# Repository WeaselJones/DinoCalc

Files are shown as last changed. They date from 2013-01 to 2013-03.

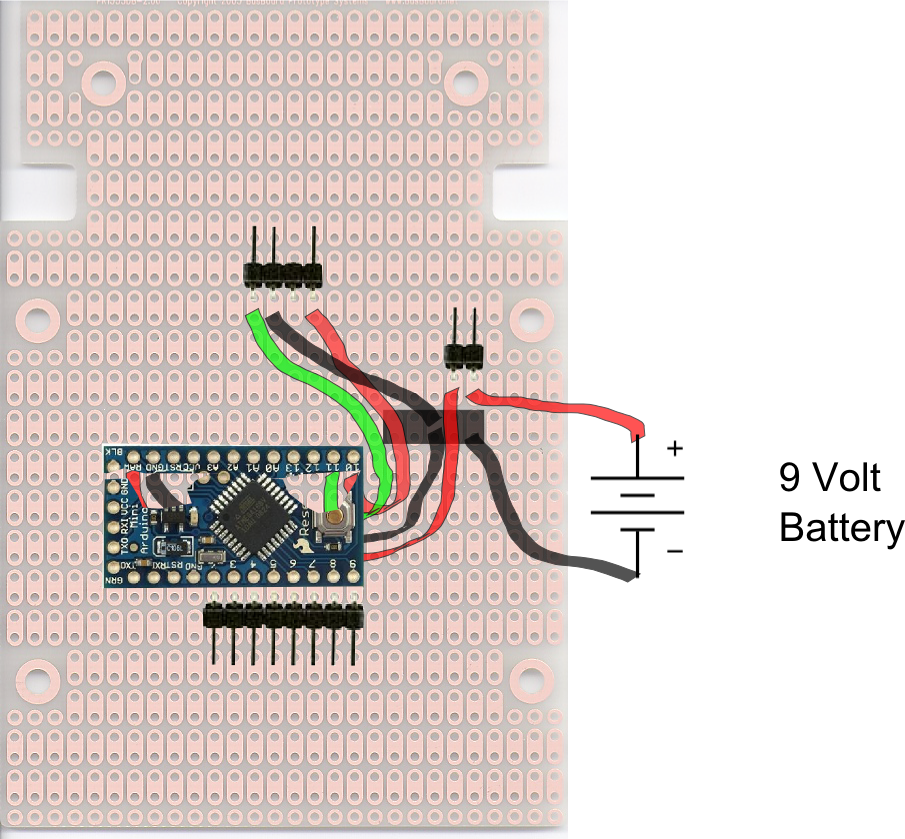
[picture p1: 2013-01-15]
Hardware/Hardware Layouts/Hardware Layout Version 1v0.png

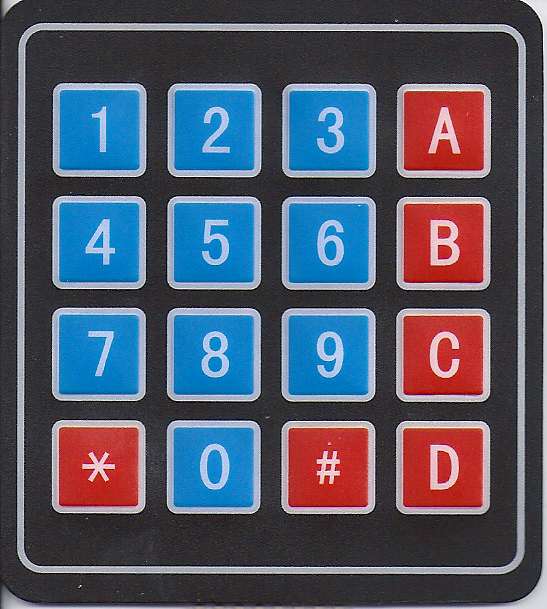
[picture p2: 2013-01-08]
Hardware/Inkscape files/4x4 keypad0001.tif

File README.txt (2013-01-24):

DinoCalculator Version 1.0

Download updates from:
http://code.google.com/p/dinocalc/

Summary:
When I was younger I had a calculator that did not have a LCD display but instead 
had two LED lights, one green and one red.  You would enter a math problem with what 
you thought the correct answer was (for example, type 12 + 12 = 24, and then press 
the "?" key).  If your answer was right the green LED would light up, if your answer 
was wrong, the red LED would light up.

This is my salute to that toy from my childhood, as well as a great way for me to 
engineer and program a neat little project that my preschool son can actually use 
to check his simple math.

This first part will document the prototype that I have built.  My first objective 
was to create a calculator capable of just adding and subtracting using off the 
shelf items.  I plan on starting with an Arduino Pro Mini for the developmental 
and prototype stage and once I can get most of the major bugs worked out I will 
then move on to a final version that has a lower cost and device count (ATmega328P
on a custom PCB).  

Future objectives (not in any particular order) will be to:

1) Replace the Arduino Pro Mini board with a custom made PCB and reduce parts to 
a minimum to lower costs (I already have several friends wanting versions for 
their kids)

2) Add multiplication and division to the calculator's capabilities (low priority 
for me since this will involve more keys then a 4x4 matrix keypad and my son is 
only starting addition and subtraction right now)

3) Develop a custom keypad (maybe using tactile buttons and caps, or making my 
own "membrane" type keypad, or exploring "conductive" type buttons)

4) Add sound for errors or beep whenever custom keypad button is pressed

5) Develop code so that it could also be used for a "math" type game for multiple 
players. For example, Display a math problem and contestants enter answer on their 
calculators. If their answer is right, their token moves away from some peril 
(like a chomping dinosaur) and if wrong moves closer to peril. Loser is the one 
that gets eaten (chomp,chomp,chomp)

6) Make the circuit low-power for longer battery life and replace the 9V battery 
with two NiMH AA batteries or perhaps even a button cell rechargeable battery

7) Add a recharging circuit to recharge the rechargeable batteries from USB

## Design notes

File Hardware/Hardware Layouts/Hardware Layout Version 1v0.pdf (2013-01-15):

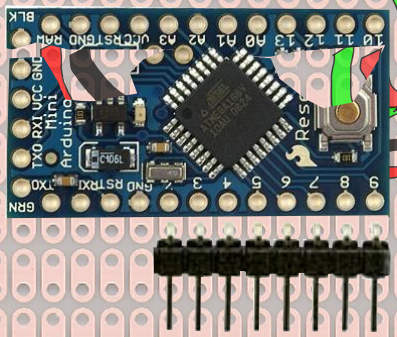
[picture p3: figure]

9 Volt
Battery

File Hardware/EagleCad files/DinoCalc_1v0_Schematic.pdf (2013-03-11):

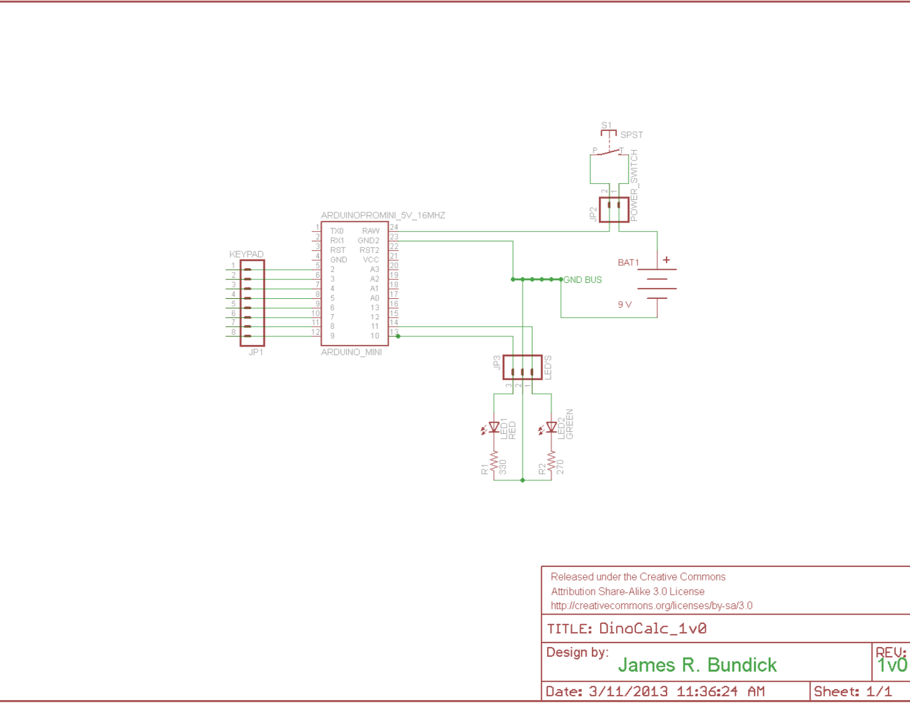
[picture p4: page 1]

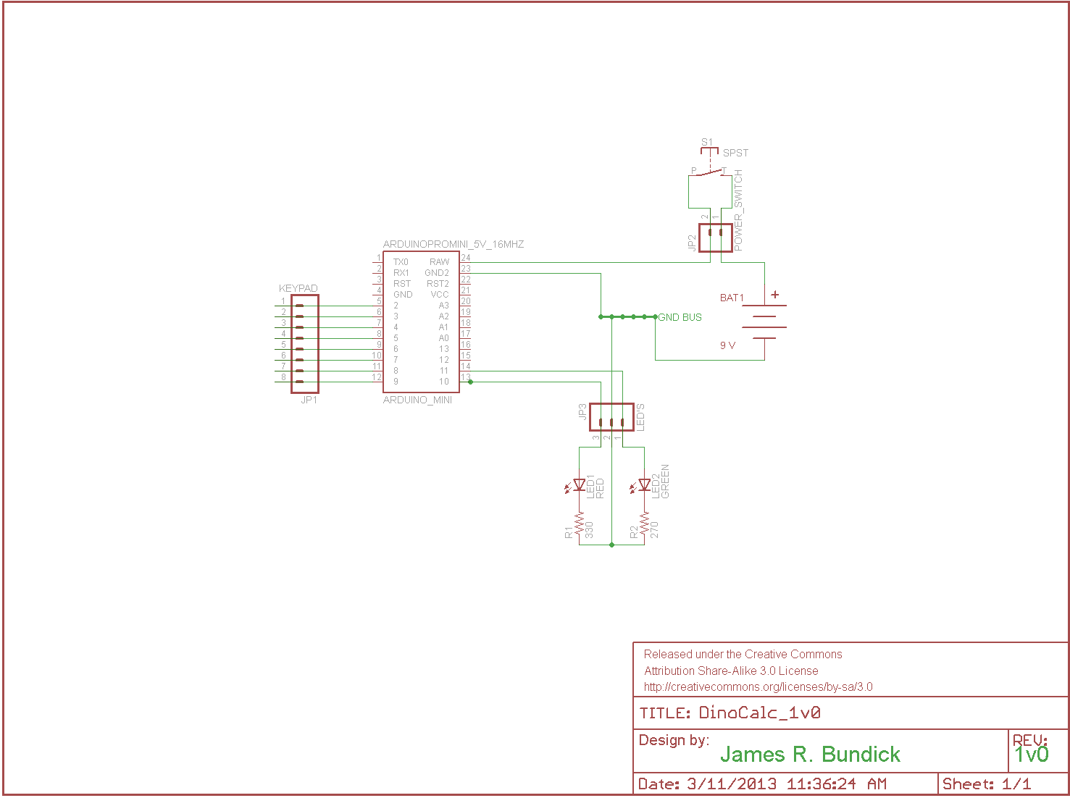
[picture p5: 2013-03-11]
Hardware/EagleCad files/DinoCalc_1v0_Schematic.png

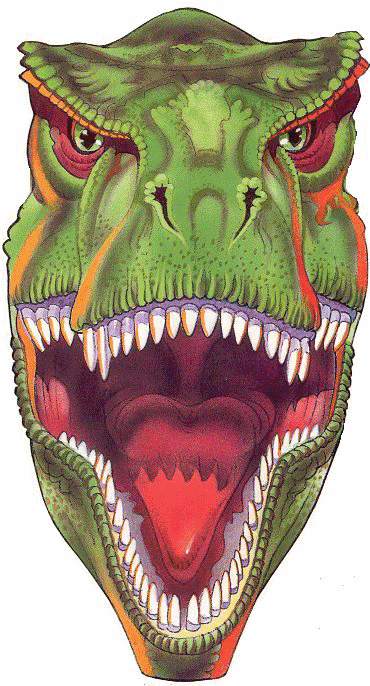
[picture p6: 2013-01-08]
Hardware/Inkscape files/face.gif

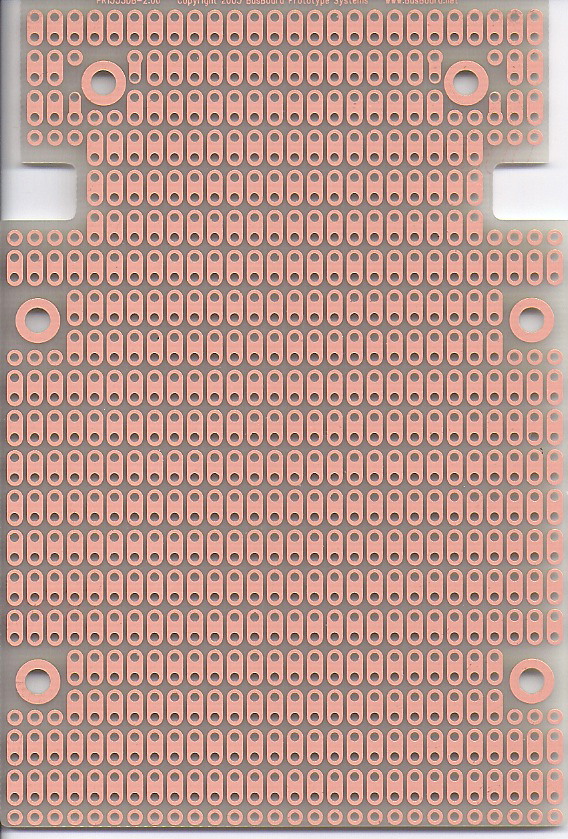
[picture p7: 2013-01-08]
Hardware/Inkscape files/Protoboard Blank Layout.tif

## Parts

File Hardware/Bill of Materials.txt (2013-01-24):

DinoCalc Hardware version 1.0 (Prototype stage)

Below is a listing of parts used in the Prototype stage of 
the DinoCalculator.  The Bill of Materials is listed in three 
parts from Mouser.com, Sparkfun.com, and Amazon.com.
Omit any parts you might already have and feel free to use
your favorite source(s) for parts.

----------------------------------------------------
BOM 1 of 3  MOUSER.COM  
----------------------------------------------------

Item
No.   Qty   Description                            Part Number
--    ---   -------------------------------------  ----------------
1)     1    9v Alkaline Battery                    658-6LR61XWA
2)     1    CARBON FILM RESISTOR - 330 OHMS        291-330-RC
3)     1    CARBON FILM RESISTOR - 270 OHMS        291-270-RC
4)     1    SPST ON-OFF SLIDE SWITCH               112-R13-602A
5)     1    LED - THROUGH HOLE GREEN DIFFUSED      78-TLHG5400
6)     1    LED - THROUGH HOLE RED DIFFUSED        78-TLHR5400
7)     2    5MM LED PANEL MOUNTING                 696-SSH-LX5091
8)     1    4X4 MATRIX MEMBRANE KEYPAD             619-27899
9)     1    PROTOTYPE BOARD FOR 1553DBKBAT ENC     854-PR1553DBAT
10)    1    HAND HELD ENC WITH BATT COMPARTMENT    546-1553DBKBAT

You can find this Bill of Material on the mouser.com website under
the DinoCalc version 1.0 project at the following link:
  
http://www.mouser.com/ProjectManager/ProjectDetail.aspx?AccessID=0904c64079

----------------------------------------------------
BOM 2 of 3  SPARKFUN.COM
----------------------------------------------------

Item
No.   Qty   Description                            Part Number
--    ---   -------------------------------------  ----------------
1)     1    Arduino Pro Mini 328 - 5V/16MHz        DEV-11113
2)     1    FTDI Basic Breakout - 5V               DEV-09716  (Optional)
3)     1    Female Headers                         PRT-00115  (Optional)
4)     1    Break Away Headers - Straight          PRT-00116
5)     1    Break Away Male Headers - Right Angle  PRT-00553  
6)     1    Solderless Headers - 10-pin Straight   PRT-10527  (Optional)
7)     1    Jumper Wire - PTH Black White          PRT-08672  (Optional)
8)     1    Jumper Wire - 0.1", 3-pin, 6"          PRT-10368  (Optional)
9)     1    Hook-up Wire - Red                     PRT-08023  (Optional)
10)    1    Hook-up Wire - Black                   PRT-08022  (Optional)

Notes:
Item #2:  This is needed if you don't already have a way to program the Arduino Pro Mini.
          DEV-09718 5V FTDI Cable will also work and you won't need to find a USB Cable.
Item #3:  This is needed if you don't want to make the Arduino Pro Mini a permanent
          installation in your calculator and you want to reuse it for a later project.
Item #6:  This can be used in place of soldering headers to the Arduino Pro Mini 
          Programming Header.
Items #7 and #8:  These are recommended only if you don't already have some old jumper 
          wires (such as CD-ROM kits or from old computer boards) laying around.
Items #9 and #10:  Hook-up Wire is needed only if you don't already have a source of 
          22 AWG wire for the wiring on the protoboard.

You can find this Bill of Material in a Wish List on Sparkfun.com at:
https://www.sparkfun.com/wish_lists/56143

----------------------------------------------------
BOM 3 of 3  AMAZON.COM
----------------------------------------------------

This was the adhesive paper purchased to place over
the keypad and on the enclosure face.

Item
No.   Qty   Description                            
--    ---   -------------------------------------  
1)     1    Avery Sticker Project Paper, White, 8.5 x 11 Inches, Pack of 15 (03383)

found at link:  http://www.amazon.com/gp/product/B0000C0CJQ/ref=oh_details_o04_s00_i00

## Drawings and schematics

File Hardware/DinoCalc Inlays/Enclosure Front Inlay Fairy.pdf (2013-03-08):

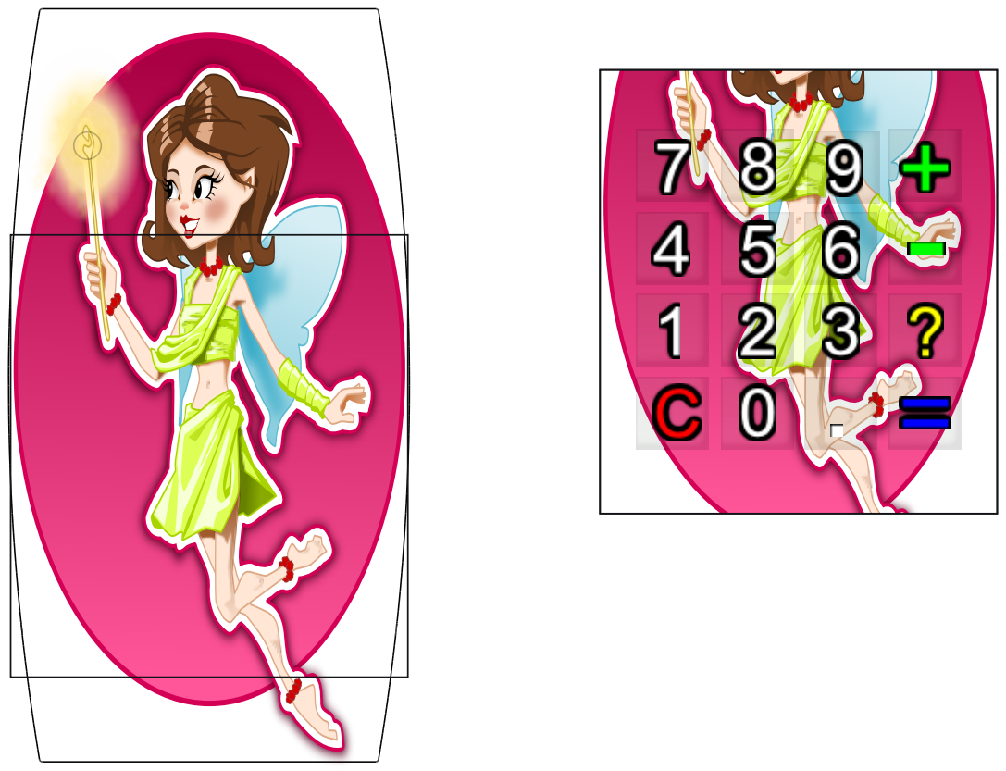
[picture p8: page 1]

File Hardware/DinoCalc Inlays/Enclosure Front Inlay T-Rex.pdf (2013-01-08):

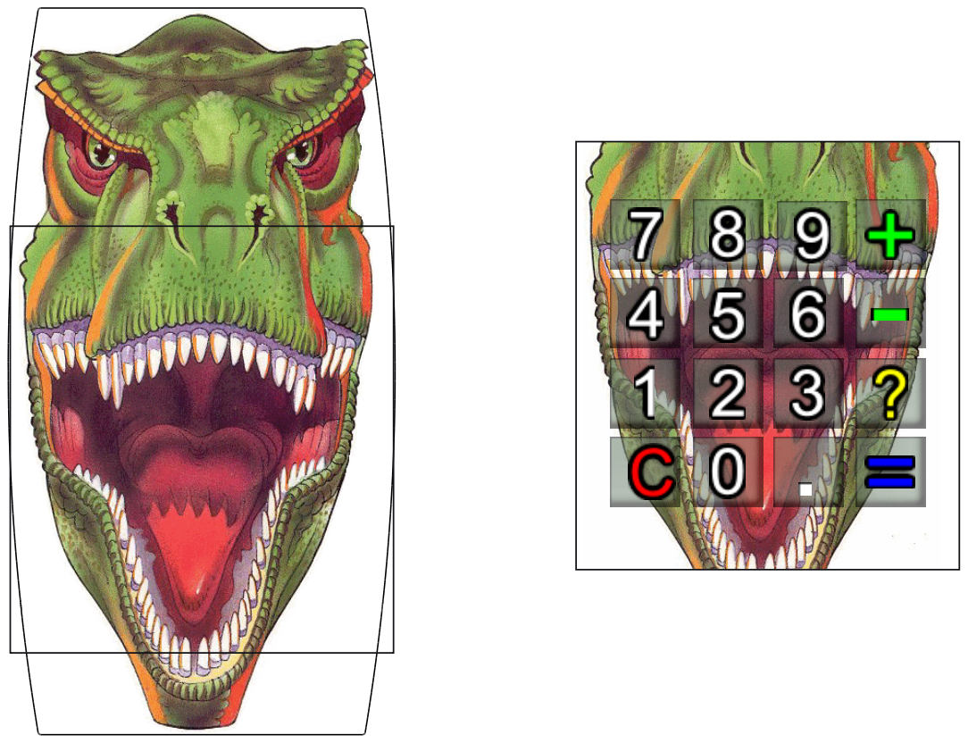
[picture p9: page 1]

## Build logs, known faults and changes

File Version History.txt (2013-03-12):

DinoCalculator Release 1v0

Hardware Version History

1.0 2012-12-31 - JRB: Prototype with Arduino Pro Mini (5V/16MHz)

Software Version History

1.0 2012-12-31 - JRB: RELEASE VERSION. Changed keypad matrix to match 
the layout I printed on the keypad sticker. Added blinkLEDs() to show 
activity when calculator is first powered ON. Commented out Serial 
commands and printInfo(), program size went from ~12,000 bytes to 
9,868 bytes.

0.5 2012-12-22 - JRB: Changed x,y,z,z2 from integers to floating
for "real" number calculations. Since floating point math is not 
completly exact http://arduino.cc/en/Reference/Float I added code 
to check that the absolute value of the difference between the 
calculated answer and the entered answer is less than some small 
number. Reformated text layout for printing.

0.4c 2012-12-22 - JRB: WORKING VERSION of adding and subtracting
whole numbers only. Negative number adding and subtracting is also 
supported. Minus key can be used for negative numbers now, not just 
subtraction. (ie, can now enter "-3 + -5 = -8")

0.4b 2012-12-21 - JRB: Added condition to prevent "?" from giving
false "correct"

0.4 2012-12-19 - JRB: Added more information to program
description. Added comparison of user entered answer to calculated answer. 
Added Green and Red LED code for correct and wrong answer results. Changed 
code to allow negative number answers.

0.3 2012-12-18 - JRB: Corrected minor string issue with equal sign attaching 
to stringOne after calculation. Cleaned up serial commands for debugging.

0.2 2012-12-17 - JRB: Worked on code to add multi-digit numbers
instead of single digit numbers by doing conversion of strings to integers.

0.1 2012-12-17 - JRB: Got Code working to read key presses of membrane 4x4 keypad. 
Serial print commands added for debugging and will be commented out when code is stable.

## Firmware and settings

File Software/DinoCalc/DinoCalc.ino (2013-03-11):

/* DinoCalc Calculator Software 1v0
   by James R. Bundick (weaseljones@gmail.com)
   Programmed using Arduino IDE 1.0.3
................................................................
License
The library, Keypad.h version 3.0, was used without modification
and is authored by Mark Stanley and Alexander Brevig
which they released under the GNU LGPL 2.1 license.

The rest of the code done by myself is released under 
the MIT License  http://opensource.org/licenses/MIT
Copyright (c) 2012 James R. Bundick

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
THE SOFTWARE IS PROVIDED "AS IS", WITHOUT WARRANTY OF ANY KIND, 
EXPRESS OR IMPLIED, INCLUDING BUT NOT LIMITED TO THE WARRANTIES 
OF MERCHANTABILITY, FITNESS FOR A PARTICULAR PURPOSE AND 
NONINFRINGEMENT. IN NO EVENT SHALL THE AUTHORS OR COPYRIGHT 
HOLDERS BE LIABLE FOR ANY CLAIM, DAMAGES OR OTHER LIABILITY, 
WHETHER IN AN ACTION OF CONTRACT, TORT OR OTHERWISE, ARISING 
FROM, OUT OF OR IN CONNECTION WITH THE SOFTWARE OR THE USE OR 
OTHER DEALINGS IN THE SOFTWARE.
................................................................

Summary:
When I was younger I had a calculator that did not have a LCD display but 
instead had two LED lights, one green and one red.  You would enter a math 
problem with what you thought the correct answer was (for example, 
12 + 12 = 24, and then press the "?" key).  If your answer was right the 
green LED would light up, if your answer was wrong, the red LED would light 
up.

This is my salute to that toy from my childhood, as well as a great way for 
me to engineer and program a neat little project that my preschool son can 
actually use to check his simple math.

This first part will document the prototype that I have built.  My first 
objective was to create a calculator capable of just adding and subtracting 
using off the shelf items.  I plan on starting with an Arduino Pro Mini for 
the developmental and prototype stage and once I can get most of the major 
bugs worked out I will then move on to a final version that has a lower cost 
and device count (ATmega328p on a custom PCB).  


Future objectives (not in any particular order) will be to:

1) Replace the Arduino Pro Mini board with a custom made PCB and reduce parts 
to a minimum to lower costs (I already have several friends wanting versions 
for their kids)

2) Add multiplication and division to the calculator's capabilities (low 
priority for me since this will involve more keys then a 4x4 matrix keypad 
and my son is only starting addition and subtraction right now)

3) Develop a custom keypad (maybe using tactile buttons and caps, or making my
own "membrane" type keypad, or exploring "conductive" type buttons)

4) Add sound for errors or beep whenever custom keypad button is pressed

5) Develop code so that it could also be used for a "math" type game for multiple
players. For example, Display a math problem and contestants enter answer on their 
calculators. If their answer is right, their token moves away from some peril (like
a chomping dinosaur) and if wrong moves closer to peril. Loser is the one that gets
eaten (chomp,chomp,chomp)

6) Make the circuit low-power for longer battery life and replace the 9V battery
with two NiMH AA batteries or perhaps even a “button” cell rechargeable battery

7) Add a recharging circuit to recharge the rechargeable batteries from USB


References used during development:
1)  http://tronixstuff.wordpress.com/tutorials  > Arduino Tutorials,
    chapter 42a, Keypads II
2)  http://www.arduino.cc/playground/Code/Keypad by Mark Stanley, 
    Alexander Brevig 
3)  "Arduino Cookbook", 2nd edition, by Michael Margolis
4)  "BlinkWithoutDelay" example by David A. Mellis and Paul 
     Soffregen that came with Arduino IDE 1.0.3 
5)  Floating number math with Arduino,
    http://arduino.cc/en/Reference/Float 

Bill of Material for prototype:
1)  Arduino Pro Mini 5V/16MHz from Sparkfun.com
2)  4x4 Matrix keypad purchased on Amazon.com
3)  Red LED
4)  Green LED
5)  330 ohm resistor, 270 ohm resistor
6)  SPST switch (used SPDT because that is what I had)
7)  Female and Male Headers (Sparkfun.com)
8)  Protobox - 1553DBAT-BK KIT from Busboard Prototye Systems
    Purchased on Amazon.com
    (Includes:  Enclosure, PCB, screws, battery clips)
9)  Hook-up Wire
10) 9V Battery
11) Avery Adhesive Sticker Paper
    Purchased on Amazon.com
12) Heat Shrink (Radio Shack)
13) LED holders (Radio Shack)

Hardware layout:
Keypad:  4x4 Matrix Membrane keypad 
          
          1  2  3  A 
          4  5  6  B
          7  8  9  C
          *  0  #  D
          
         Each Row and Each Column connects to a PIN for total of 
         8 pins.
         Row 1 >> Pin 1      Column 1 >> Pin 5
         Row 2 >> Pin 2      Column 2 >> Pin 6
         Row 3 >> Pin 3      Column 3 >> Pin 7
         Row 4 >> Pin 4      Column 4 >> Pin 8

Arduino D 2 ---> 4x4 keypad pin 1
Arduino D 3 ---> 4x4 keypad pin 2
Arduino D 4 ---> 4x4 keypad pin 3
Arduino D 5 ---> 4x4 keypad pin 4
Arduino D 6 ---> 4x4 keypad pin 5
Arduino D 7 ---> 4x4 keypad pin 6
Arduino D 8 ---> 4x4 keypad pin 7
Arduino D 9 ---> 4x4 keypad pin 8
Arduino D10 ---> (long leg)RED LED(short leg) ---> 
                     330 ohm resistor ---> GND
Arduino D11 ---> (long leg)GRN LED(short leg) ---> 
                     270 ohm resistor ---> GND


Software Logic

1) User enters First Number, then math operator, then Second
   Number, then equal sign, then user's answer, then "?"
   [12 + 12 = 12 ? <-- User's guess]
2) Microprocessor calculates answer to First Number, math 
   operator, Second Number 
   [12 + 12 = 24  <-- Calculated answer]
3) Microprocessor compares calculated answer to  User Inputed 
   Answer.  If they are not equal then light red LED.  If they
   are equal then light green LED. 
   [12 != 24, so light red LED]

Version History
1.0  2012-12-31 - JRB:  RELEASE VERSION.  Changed keypad matrix to
      match the layout I printed on the keypad sticker.  Added
      blinkLEDs() to show activity when calculator is first powered
      ON.  Commented out Serial commands and printInfo(), program
      size went from ~12,000 bytes  to 9,868 bytes.
      
0.5  2012-12-22 - JRB:  Changed x,y,z,z2 from integers to floating
      for "real" number calculations. Since floating point math
      is not completly exact http://arduino.cc/en/Reference/Float 
      I added code to check that the absolute value of the 
      difference between the calculated answer and the entered 
      answer is less than some small number.  
      Reformated text layout for printing.

0.4c 2012-12-22 - JRB:  WORKING VERSION of adding and subtracting
      whole numbers only.  Negative number adding and subtracting
      is also supported.  Minus key can be used for negative 
      numbers now, not just subtraction. 
      (ie, can now enter "-3 + -5 = -8")
           
0.4b 2012-12-21 - JRB: Added condition to prevent "?" from giving
      false "correct"

0.4 2012-12-19 - JRB: Added more information to program 
      description.  Added comparison of user entered answer to 
      calculated answer.  Added Green and Red LED code for 
      correct and wrong answer results.  Changed code to allow 
      negative number answers.
                      

0.3 2012-12-18 - JRB: Corrected minor string issue with equal sign
      attaching to stringOne after calculation.  Cleaned up serial
      commands for debugging.

0.2 2012-12-17 - JRB: Worked on code to add multi-digit numbers 
      instead of single digit numbers by doing conversion of 
      strings to integers.

0.1 2012-12-17 - JRB: Got Code working to read key presses of 
      membrane 4x4 keypad.  Serial print commands added for 
      debugging and will be commented out when code is stable.

*/

#include "Keypad.h" // http://www.arduino.cc/playground/Code/Keypad by Mark Stanley, Alexander Brevig 
    

const byte ROWS = 4; //four rows
const byte COLS = 4; //four columns
char keys[ROWS][COLS] =
 {{'7','8','9','+'}, //Sticker will be applied over keypad to 
  {'4','5','6','-'}, //match the layout I want and to provide 
  {'1','2','3','?'}, //a custom graphic (eg dinosaur, bird, etc)
  {'C','0','.','='}};// 
byte rowPins[ROWS] = {
  2, 3, 4, 5}; //Arduino pins that connect to the row pinouts of the keypad pins 1 through 4.
byte colPins[COLS] = {
  6, 7, 8, 9}; //Arduino pins that connect to the column pinouts of the keypad pins 5 through 8.

Keypad keypad = Keypad(makeKeymap(keys), rowPins, colPins, ROWS, COLS);

const int ledGRN = 11;  //Arduino output for Green LED
const int ledRED = 10;  //Arduino output for Red LED

long previousMillis = 0; //used to light LED without using delay()
long interval = 3000;  //maximum time to leave LED HIGH (on)

float x; //first number that is entered by user
float y; //second number that is entered by user
float z; //calculated answer
float z2; //answer that is entered by user
int h;  //used to indicate if "." has been pressed already
int i;  //placeholder for operator (i=1 for addition, i=2 for subtraction)
int j;  //used to indicate to program that it is time for the user to input an answer

String stringOne;   //Placeholder for First Number entered by user
String stringTwo;   //Placeholder for Second Number entered by user                                                     
String stringThree; //stringThree is used to show operator and if equal has been pressed.
String stringFour;  //Placeholder for Guessed Answer entered by user                                                     
                                                       
void setup()
{
//  Serial.begin(9600); //for debugging

  pinMode (ledGRN, OUTPUT); //sets up the Arduino pins as outputs
  pinMode (ledRED, OUTPUT);
  
  stringOne = String ();
  stringTwo = String ();
  stringThree = String ();
  stringFour = String ();

  x = 0;
  y = 0;
  z = 0;
  z2 = 0;
  h = 0;
  i = 0;
  j = 0;
  blinkLEDs();
}

void loop()
{
  unsigned long currentMillis = millis();       //Make sure LED doesn't stay continuously on, 
  if(currentMillis - previousMillis > interval) //but allow the code to continue without a delay.
  {                                             
    digitalWrite (ledGRN, LOW);                 
    digitalWrite (ledRED, LOW);                 
  }


  char key = keypad.getKey();
  switch (key)
  {
    case 'C':    //If 'C' is pressed then clear calculator
      blinkLEDs();
      clearCalc();
      break;
    
    case '?':    //Calculate answer and compare it to the answer that was entered by the user
      if (j == 3)
      {
        calcAnswer();
      }
      else
      {
        stringThree = "ERROR";  //if '?' is pressed too soon, error out
//        printInfo();
        showError();
        clearCalc();
      }
      break;
    
    case '=':    //Get ready for the answer to be entered by user
      if (j == 2)
      {
        h = 0;  //h = 0 to allow "." to be used in Answer
        j = 3;  //change j to 3 when equal key has been used once
        stringThree = stringThree + key;
//        printInfo();
      }    
      else
      {
        stringThree = "ERROR";  //if equal is pressed too soon, error out
//        printInfo();
        showError();
        clearCalc();
      }
      break;

    case '+':
      if (i == 0)
      {
        h = 0;  //h = 0 to allow "." to be used for Number2
        i = 1;  //i = 1 to denote addition
        j = 1;  //j = 1 to indicate operator has been pressed, now get Number2
        stringThree = stringThree + key;
//        printInfo();
      }    
      else
      {
        stringThree = "ERROR"; //if plus is pressed multiple times, error out
//        printInfo();
        showError();
        clearCalc();
      }
      break;
  
    case '-':
      if (i == 0)
      {
        if (stringOne == "") //If '-' is the first digit pressed for Number1,
        {                    //use '-' to indicate Number1 is a negative number
          stringOne = stringOne + key;
        }
        else
        {
          h = 0;  //h = 0 to allow "." to be used for Number2
          i = 2;  //i = 2 to denote subtraction
          j = 1;  //j = 1 to indicate operator has been pressed, now get Number2
          stringThree = stringThree + key;
        }
//        printInfo();  
      }    
      else
      {
        if (j == 3 && stringFour == "")  //equal key has been pressed once,
        {                                //if '-' is first digit of answer,
          stringFour = stringFour + key; //answer is a negative number
//          printInfo();
        }
        else
        {
          if (stringTwo == "") //if '-' is first digit of Number2, Number2 is a negative number
          {
            stringTwo = stringTwo + key;
//            printInfo();
          }
          else
          {
            stringThree = "ERROR";  //if minus is pressed and is not operator or first digit of number, error out
//            printInfo();
            showError();
            clearCalc();
          }
        }
      }
      break;
  
    case '.':
      if (h == 0)
      {
        h = 1;  //denotes a decimal point has been used once
        if (j == 0)
        {
          stringOne = stringOne + key; //adds decimal to Number1
        }
        if (j == 1 || j == 2)
        {
          stringTwo = stringTwo + key; //adds decimal to Number2
        }
        if (j == 3)
        {
          stringFour = stringFour + key; //adds decimal to Answer
        }
//        printInfo();
     }
     else
     {
       stringThree = "ERROR";  //if you try and enter a second decimal point in a number, error out
//       printInfo();
       showError();
       clearCalc();
     }
     break;

    default:
      if (key != NO_KEY)
      {
        digitalWrite (ledGRN, LOW); //Turn off LED's if they are on
        digitalWrite (ledRED, LOW);

        if (i == 0) //entering Number1
        {
          stringOne = stringOne + key;
        }
        if ((i == 1 || i == 2) && j != 3) //entering Number2, '=' has not been pressed
        {
          stringTwo = stringTwo + key;
          j = 2; //indicated operator has already been used
        }
        if (j == 3) //'=' has been pressed, entering User's answer
        {
          stringFour = stringFour + key;
        }
//        printInfo();
    }
  }
}

void calcAnswer ()  //Calculate answer and compare to user's answer
{
  char charBufx[50]; //might be able to reduce number from 50
  char charBufy[50];
  char charBufz2[50];
  stringOne.toCharArray(charBufx,50);   //convert String to char array
  stringTwo.toCharArray(charBufy,50);   //convert String to char array
  stringFour.toCharArray(charBufz2,50); //convert String to char array

  x = atof(charBufx);   //convert char array to float
  y = atof(charBufy);   //convert char array to float
  z2 = atof(charBufz2); //convert char array to float

  if (i == 1) //operator was addition
  {
    z = x + y;  //Calculate answer
    stringThree = " + ";
  }
  if (i == 2) //operator was subtraction
  {
    z = x - y;  //Calculate answer
    stringThree = " - ";
  }

  float a;     
  a = z2 - z;  //since floating point math is not completly exact, http://arduino.cc/en/Reference/Float 
               //check that the absolute value of the difference between the numbers is less than some small number. 

//.......................................................
//  Print to Serial for Debugging
/*    Serial.print ("\nCalculated answer:");
    Serial.print (x,4);
    Serial.print (stringThree);
    Serial.print (y,4);
    Serial.print (" = ");
    Serial.print (z,4);
    Serial.print ("\nEntered answer:");
    Serial.print (x,4);
    Serial.print (stringThree);
    Serial.print (y,4);
    Serial.print (" = ");
    Serial.print (z2,4);
    Serial.print ("\nDifference between answers:"); 
    Serial.print (a,12);
*/    
//.......................................................
 
  if (abs(a) < 0.000001) //since floating point math is not completly exact http://arduino.cc/en/Reference/Float 
  {                      //check that the absolute value of the difference between the numbers is less than some small number. 
//    Serial.print ("\nCORRECT!!!"); //for Debugging
    digitalWrite (ledGRN, HIGH);
    digitalWrite (ledRED, LOW);
    previousMillis = millis();   
  }
  else
  {
//    Serial.print ("\nWRONG!!!");  //for Debugging
    digitalWrite (ledGRN, LOW);
    digitalWrite (ledRED, HIGH);
    previousMillis = millis();   
  }
  clearCalc();  //get ready for next math problem
}

/*void printInfo ()  //Used for Debugging
{
     Serial.print ("\nString1 : ");
     Serial.println (stringOne);
     Serial.print ("\nString2 : ");
     Serial.println (stringTwo);
     Serial.print ("\nString3 : ");
     Serial.println (stringThree);
     Serial.print ("\nString4 : ");
     Serial.println (stringFour);
}
*/

void clearCalc() //Get ready for next math problem
{
    Serial.println ("\ncleared\n\n\n");  //for debugging

    stringOne = "";
    stringTwo = "";
    stringThree = "";
    stringFour = "";
    x = 0;
    y = 0;
    z = 0;
    h = 0;
    z2 = 0;
    i = 0;
    j = 0;
     
   char key = NO_KEY;
}

void showError() //Blink RED LED to show Errors
{
  for (int k=0; k <10; k++) 
  {
    digitalWrite (ledGRN, LOW);
    digitalWrite (ledRED, HIGH);
    delay (50);
    digitalWrite (ledGRN, LOW);
    digitalWrite (ledRED, LOW);
    delay (50);
  }   
}

void blinkLEDs()
{
  for (int k=0; k <5; k++) //flash LED's so you know something is going on
  {
    digitalWrite (ledGRN, HIGH);
    digitalWrite (ledRED, HIGH);
    delay (50);
    digitalWrite (ledGRN, LOW);
    digitalWrite (ledRED, LOW);
    delay (50);
  }  
} 

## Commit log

2013-01-04 Bill of Material link to Mouser.com
2013-01-07 Create Sparkfun BOM
2013-01-07 Update Hardware/Sparkfun BOM
2013-01-07 Create Sparkfun BOM.txt
2013-01-07 mark for deletion.... replaced by sparkfun bom.txt
2013-01-07 Update Hardware/Link to BOM.txt
2013-01-07 Update Hardware/Sparkfun BOM.txt
2013-01-08 Combined Bill of Materials into one text file
2013-01-12 Update Hardware/Bill of Materials.txt
2013-01-18 Added Protoboard/Enclosure Kit Datasheet
    Datasheet has Protoboard picture at actual size
2013-01-24 Update to BOM 1v0
2013-03-11 Reorganized Files and Updated BOM
2013-03-11 Add EagleCad Schematic for Hardware version 1
    [DinoCalc_1v0.sch]
2013-03-11 Updated Software Comments
    Changed "Arduino pin 2" thru "Arduino pin 11" to "Arduino D 2" thru
    "Arduino D11" to prevent confusion with digital pin 2 on the Arduino and
    actual pin 2 on the Atmega 328P chip.
    [DinoCalc.ino]
2013-03-11 Attached version numbers to software files
2013-03-11 Added png picture of EagleCad Schematic
    For people without EagleCad
2013-03-11 Created pdf of EagleCad Schematic
